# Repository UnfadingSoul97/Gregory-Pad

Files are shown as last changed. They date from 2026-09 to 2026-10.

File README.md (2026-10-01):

# Gregory-Pad
# 🚀 Custom 4x4 Mechanical Macro Pad

Welcome to my custom-engineered 4x4 macro pad project, designed as part of the **Hack Club Stardance/Hackpad** mission! This device features an ortholinear key matrix, advanced anti-ghosting rotary encoder input, and a high-resolution OLED status display screen.

---

## 🛠️ Hardware Specifications

- **Microcontroller:** Seeed Studio XIAO 
- **Key Layout:** 16-key (4x4 Matrix) uniform arrangement (custom `19.69 mm` spacing)
- **Key Switches:**  Gateron KS-3X1 Milky Yellow Pro Linear Switches with Kailh Hotswap Sockets
- **Accessory Cluster:** 
  - 1x Rotary Encoder Volume Dial (equipped with anti-ghosting input isolation diodes `D17` and `D18`)
  - 1x Waveshare 1.5-inch OLED Display Module (`26.86 mm` active square glass window)

---

## 📐 Enclosure Design & Architecture

The chassis is designed completely from scratch using **Onshape** using a highly rigid **Bottom-Up Sandwich Mount System**. My PCB is 110x110mm with curved edges

- **Layer Breakdown:**
  - **Top Bezel Cap:** 4.5mm thick protective frame with a flush 9mm encoder dial portal and a custom 27.5mm tolerance screen window. Totally clean top face with hidden screw anchors.
  - **Middle Spacer Walls:** 13mm thick hollow wall ring with integrated rounded internal corner fillets designed to smoothly scatter the underglow light from the RGB LED strip. Features an inline 15mm x 8.5mm side-mounted USB-C pass-through tunnel for maximum cable mold clearance.
  - **Bottom Base Plate:** 6mm thick solid floor slab featuring 4 deep mechanical counterbore screw pockets to hide the mounting hardware heads completely flush with the desk surface.
- **Tolerances:** Applied a micro-precise `0.4 mm` gap buffer across all internal pocket steps to easily absorb 3D printing plastic cooling shrinkage without component binding.

---

## 📂 Project Repository Structure

- `/KiCad/` - Contains the electrical schematic diagram sheets, netlists, trace footprints, and production Gerber fabrication zip bundles.
- `/CAD/` - Houses the 3D-printable `.STL` and `.STEP` mechanical mesh file models exported from Onshape.
- `README.md` - Documentation guide for my hardware build.

---

## 🎮 How to Assemble (My Build Process)

1. **The Circuit Module:** Solder the 1N4148 matrix diodes and hot-swap sockets onto the underside back face of the custom PCB. Solder the Seeed Studio XIAO module onto its dedicated landing pads.
2. **Switch Plate Assembly:** Click all 16 Gateron switches directly into the 1.5mm grey switch plate, then firmly press the completed PCB against the bottom pins until they securely seat into the friction-fit hotswap contacts.
3. **Chassis Fitment:** Drop the unified switch/PCB module down onto the internal wall shelf step of the lower middle case walls.
4. **Final Clamping:** Drop the long machine screws up through the bottom
   
## 🖼️ Image of Gregory
   

## 🖼️ Image of Schematic
   

## 🖼️ Image of PCB Design 
   

## 🖼️ How to fit
   Top Plate can be fitted on top of the switch plate 
   
   First PCB and switch plate are joined together and the switches places and then screwed on to the middle body from the top.(with an m2.2 screw)
   
   The Base,Middle body and top plate are screwed form the bottom with an m.3 screw and it is 19 mm deep.
   
   The switch plate fits inside the the top plate so it looks clean but u can view the top screws from the top.Its to 3d print the same size curves and place then into 
   a arm rest or accessory as per preference.
   

## BOM 👀
1x 1 SEEEDUINO XIAO RP2040

16x Gateron KS-3X1 Milky Yellow Pro (https://stackskb.com/store/gateron-ks-3x1p-pro-yellows/)

1x SSD1327 128x128 Oled display (5V VCC, 3.3V logic, I2C)(https://www.waveshare.com/1.5inch-oled-module.htm)

18x N4148 Switching Diodes

16x Kailh Hotswap Switch Sockets

4x 19mm long m3 screws

4x 3mm long m2.2 screws

1x Rotatory Encoder(Without Switch cuz no switch pins)

1x WS2812B RGB LED Strip (Addressable underglow) (https://harishprojects.com/products/ws2812b-rgb-strip-light-programmable-pixel-led-light-5-meter-length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)

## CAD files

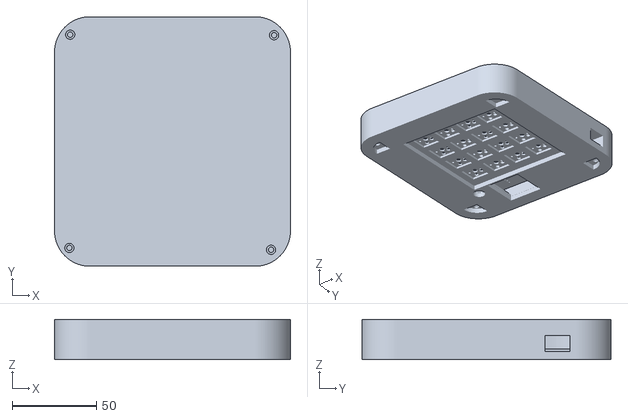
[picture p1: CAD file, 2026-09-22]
CAD/Gregory Assembled case.stl
140.0 x 148.0 x 24.0

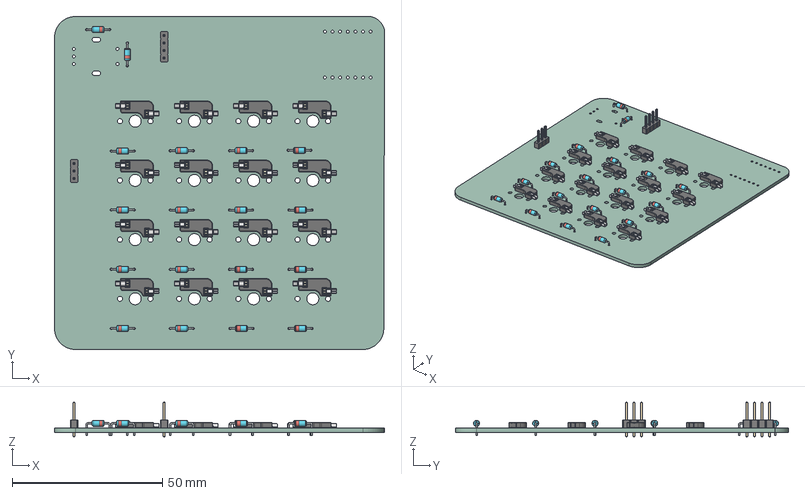
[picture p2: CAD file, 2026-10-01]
PCB/Gregory.step
109.8 x 110.8 x 11.5 mm
Kailh Socket v12 x 16
PinHeader_1x04_P254mm_Vertical
D_DO-35_SOD27_P7.62mm_Horizontal x 18
PinHeader_1x03_P254mm_Vertical
Gregory_PCB

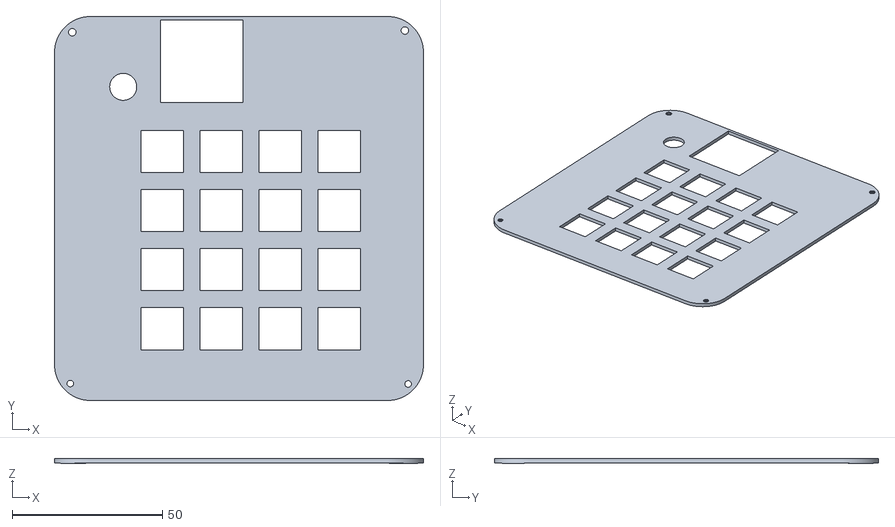
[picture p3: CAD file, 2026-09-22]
Production/Gregory Switch plate.stl
123.0 x 128.0 x 1.50

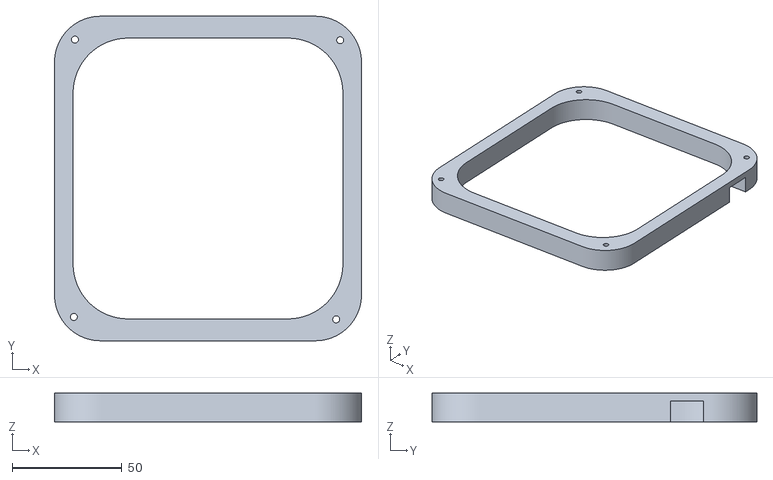
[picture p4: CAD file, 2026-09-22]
Production/Gregory Middle body.stl
140.0 x 148.0 x 13.0

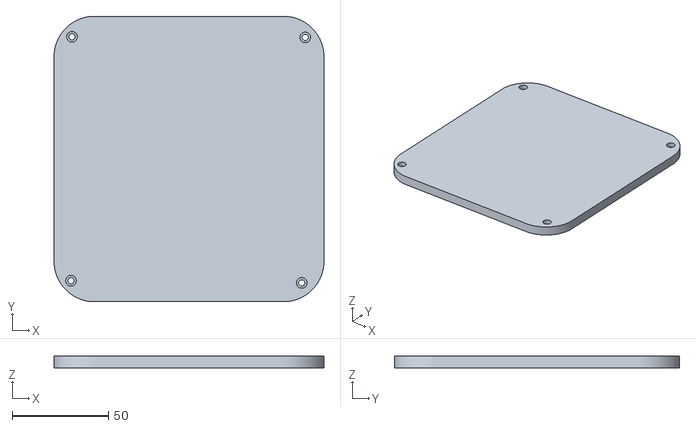
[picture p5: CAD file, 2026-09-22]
Production/Gregory base body.stl
140.0 x 148.0 x 6.00

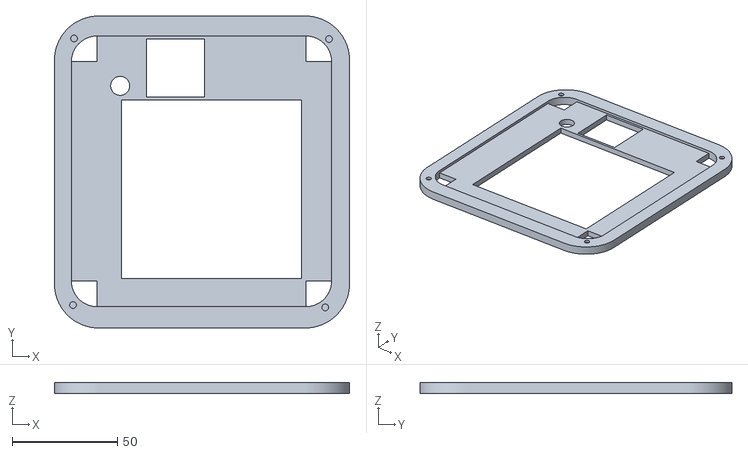
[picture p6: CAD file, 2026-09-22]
Production/Gregory Top plate bezzle.stl
140.0 x 148.0 x 5.00

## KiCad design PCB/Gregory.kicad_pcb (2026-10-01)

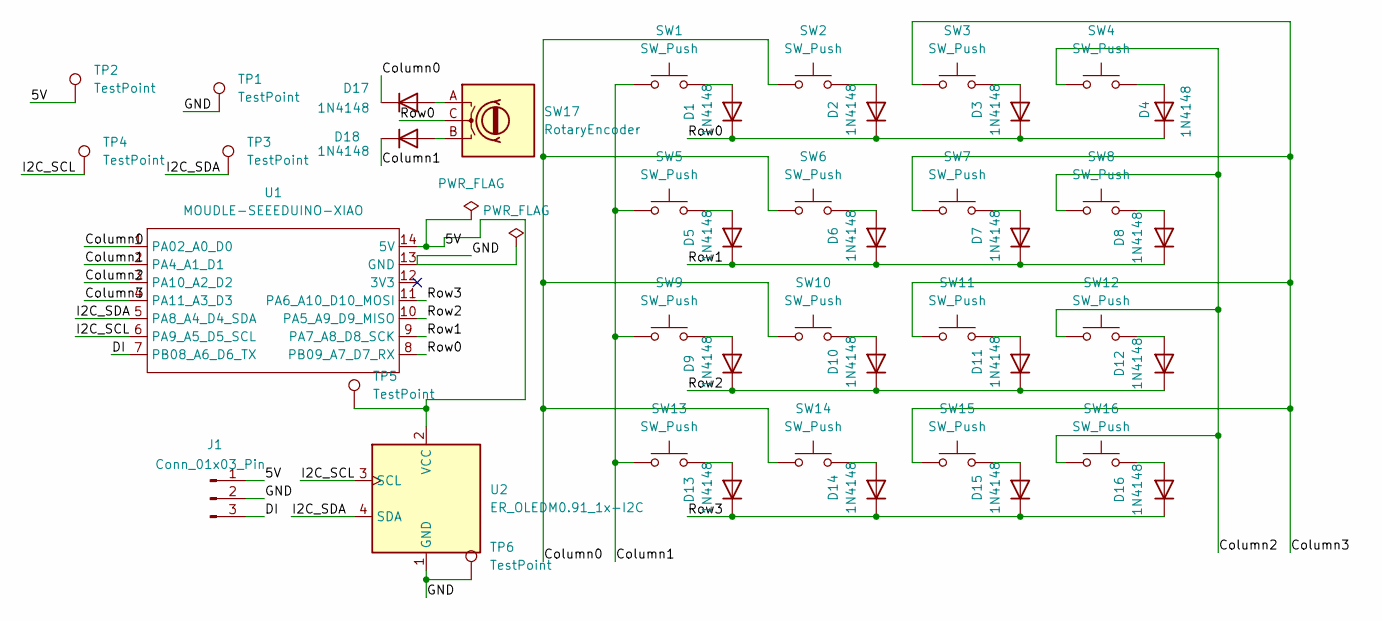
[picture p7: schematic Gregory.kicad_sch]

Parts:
D1, D2, D3, D4, D5, D6, D7, D8, D9, D10, D11, D12, D13, D14, D15, D16, D17, D18: 1N4148; D_DO-35_SOD27_P7.62mm_Horizontal
J1: Conn_01x03_Pin; PinHeader_1x03_P2.54mm_Vertical
SW1, SW2, SW3, SW4, SW5, SW6, SW7, SW8, SW9, SW10, SW11, SW12, SW13, SW14, SW15, SW16: SW_Push; MX-Hotswap-1U
SW17: RotaryEncoder; RotaryEncoder_Alps_EC11E_Vertical_H20mm
TP1, TP2, TP3, TP4, TP5, TP6: TestPoint; TestPoint_Pad_D1.5mm
U1: MOUDLE-SEEEDUINO-XIAO; XIAO-Generic-Hybrid-14P-2.54-21X17.8MM
U2: ER_OLEDM0.91_1x-I2C; PinHeader_1x04_P2.54mm_Vertical

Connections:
/5V: J1.1, TP2.1 (1_1), TP5.1 (1_1), U1.14 (5V), U2.2 (VCC)
/Column0: D17.1 (K), SW2.1, SW6.1, SW10.1, SW14.1, U1.1 (PA02_A0_D0)
/Column1: D18.1 (K), SW1.1, SW5.1, SW9.1, SW13.1, U1.2 (PA4_A1_D1)
/Column2: SW4.1, SW8.1, SW12.1, SW16.1, U1.3 (PA10_A2_D2)
/Column3: SW3.1, SW7.1, SW11.1, SW15.1, U1.4 (PA11_A3_D3)
/DI: J1.3, U1.7 (PB08_A6_D6_TX)
/GND: J1.2, TP1.1 (1_1), TP6.1 (1_1), U1.13 (GND), U2.1 (GND)
/I2C_SCL: TP4.1 (1_1), U1.6 (PA9_A5_D5_SCL), U2.3 (SCL)
/I2C_SDA: TP3.1 (1_1), U1.5 (PA8_A4_D4_SDA), U2.4 (SDA)
/Row0: D1.1 (K), D2.1 (K), D3.1 (K), D4.1 (K), SW17.C, U1.8 (PB09_A7_D7_RX)
/Row1: D5.1 (K), D6.1 (K), D7.1 (K), D8.1 (K), U1.9 (PA7_A8_D8_SCK)
/Row2: D9.1 (K), D10.1 (K), D11.1 (K), D12.1 (K), U1.10 (PA5_A9_D9_MISO)
/Row3: D13.1 (K), D14.1 (K), D15.1 (K), D16.1 (K), U1.11 (PA6_A10_D10_MOSI)
unnamed: D1.2 (A), SW1.2
unnamed: D2.2 (A), SW2.2
unnamed: D3.2 (A), SW3.2
unnamed: D4.2 (A), SW4.2
unnamed: D5.2 (A), SW5.2
unnamed: D6.2 (A), SW6.2
unnamed: D7.2 (A), SW7.2
unnamed: D8.2 (A), SW8.2
unnamed: D9.2 (A), SW9.2
unnamed: D10.2 (A), SW10.2
unnamed: D11.2 (A), SW11.2
unnamed: D12.2 (A), SW12.2
unnamed: D13.2 (A), SW13.2
unnamed: D14.2 (A), SW14.2
unnamed: D15.2 (A), SW15.2
unnamed: D16.2 (A), SW16.2
unnamed: D17.2 (A), SW17.A
unnamed: D18.2 (A), SW17.B

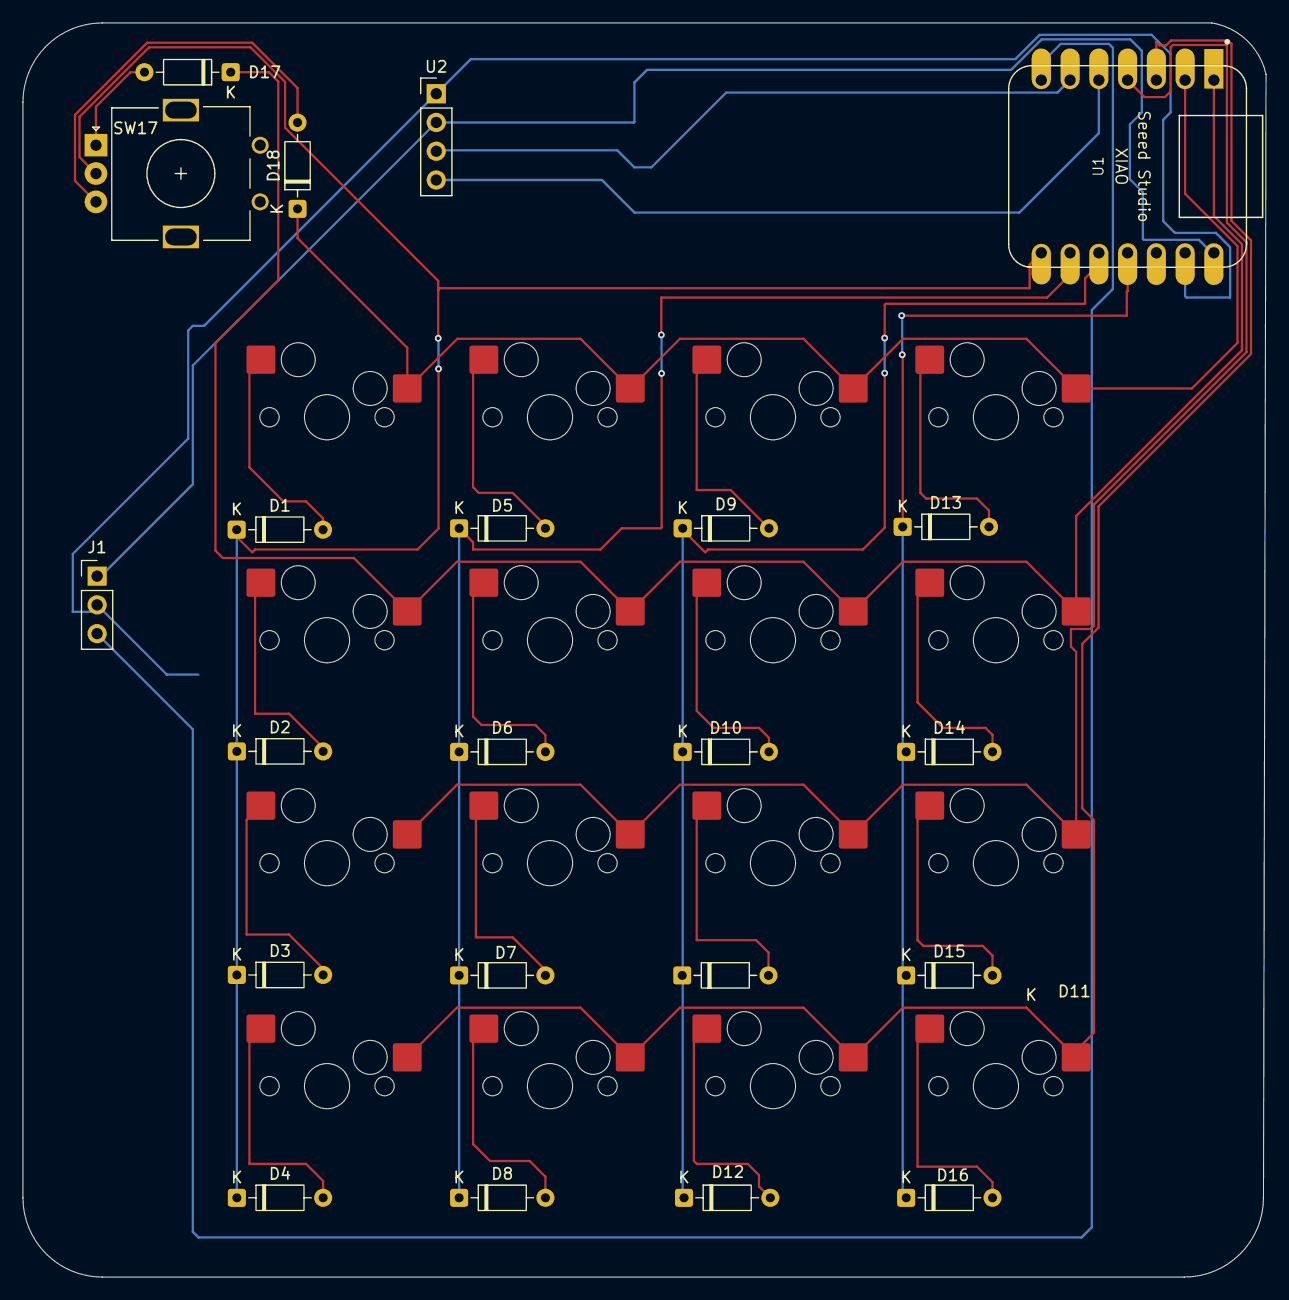
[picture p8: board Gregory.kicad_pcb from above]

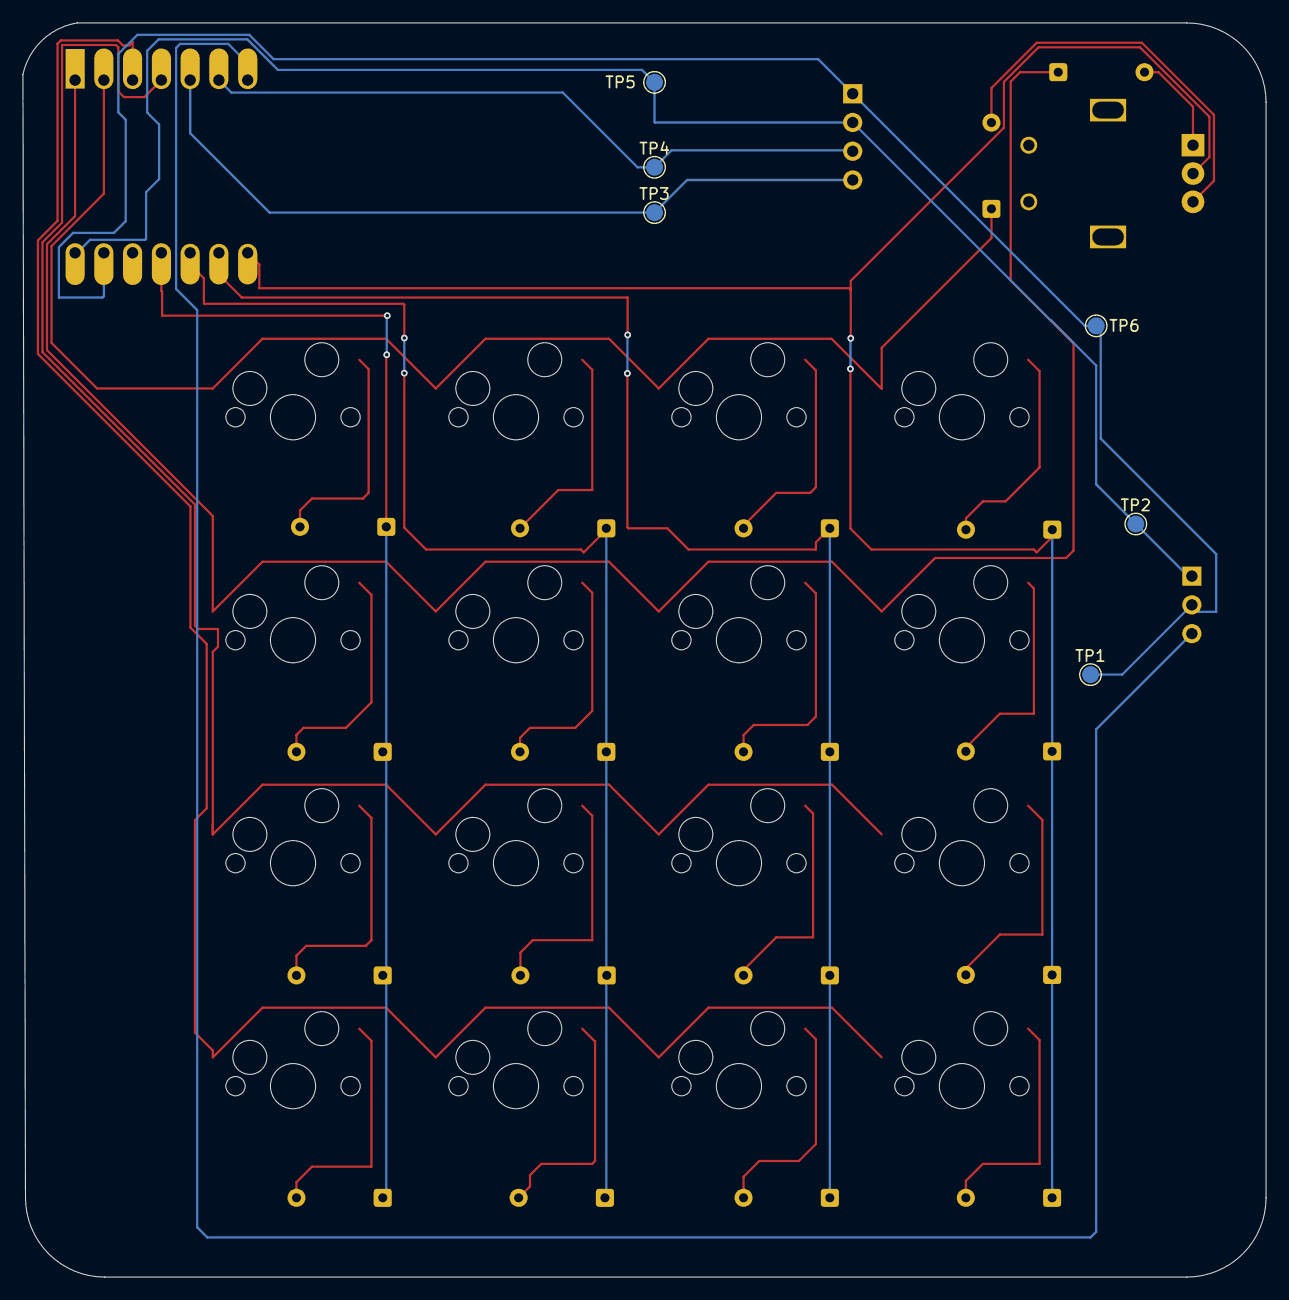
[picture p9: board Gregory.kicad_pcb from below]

Board: 2 copper layers, 109.8 x 110.8 mm, 44 parts (6 on the bottom side), 31 nets.

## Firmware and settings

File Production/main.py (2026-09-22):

import board
from kmk.kmk_keyboard import KMKKeyboard
from kmk.keys import KC
from kmk.scanners import DiodeOrientation
from kmk.modules.encoder import EncoderHandler
from kmk.extensions.rgb import RGB, AnimationModes

# Initialize the keyboard base engine
keyboard = KMKKeyboard()

# Configure your 4x4 matrix pin paths exactly to match your KiCad schematic
keyboard.col_pins = (board.D0, board.D1, board.D2, board.D3)
keyboard.row_pins = (board.D7, board.D8, board.D9, board.D10)

# Set your diode scanning direction (pointing from switches down to columns)
keyboard.diode_orientation = DiodeOrientation.COL2ROW

# Initialize the anti-ghosting volume wheel handler module
encoders = EncoderHandler()
keyboard.modules.append(encoders)

# Map your rotary encoder pin highways (Pin A, Pin B)
# Assumes DI goes to D6 and the other encoder pin goes to D5
encoders.pins = (
    (board.D6, board.D5, None, False), # (Pin A, Pin B, Click Pin, Is Inverted)
)

# Define your custom key bindings layout map (Layer 0)
keyboard.keymap = [
    [
        KC.N7, KC.N8, KC.N9, KC.MINUS,
        KC.N4, KC.N5, KC.N6, KC.PLUS,
        KC.N1, KC.N2, KC.N3, KC.SLASH,
        KC.N0, KC.DOT, KC.ENT, KC.SPC,
    ]
]

# Map your rotary encoder spinning actions to system media audio channels
encoders.map = [
    ( (KC.VOLU, KC.VOLD), ) # (Spin Clockwise = Vol Up, Spin Counter-Clockwise = Vol Down)
]

rgb = RGB(
    pixel_pin=board.D4,        # <-- Update this to the exact pin you wired to the RGB data line in KiCad!
    num_pixels=8,             # <-- Change this to the exact number of LEDs on your physical strip segment
    val_limit=150,            # Max brightness pad safety limiter (Saves battery/power load from the USB port)
    animation_mode=AnimationModes.RAINBOW, # Boots up with the classic gamer rainbow wave cycle effect
)
keyboard.extensions.append(rgb)

keyboard.extensions.append(rgb)

if __name__ == '__main__':
    keyboard.go()

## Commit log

2026-09-22 Correct switch type in assembly instructions
    Updated switch type from Leobog to Gateron in assembly instructions.
2026-09-22 Create PCB
2026-09-23 Finished the BOm and Addes steps to assemble the pad
    Added images and fitting instructions for assembly.
2026-10-01 Needed to fix the diodes they were inverted
2026-10-01 Had to fix the diodes placement cuz theyere inverted
2026-10-01 Replace PCB design image and add fitting details
    Updated PCB design image and added fitting instructions.
2026-11-04 didnt remove stl cuz though somone might need it
2026-11-04 Updated PCB file
2026-11-04 Standardize formatting in BOM.csv
    Formatted item entries for consistency in BOM.csv.
2026-11-04 Replace last row with N/A in BOM.csv
    Updated BOM.csv to replace the last row with N/A values.
2026-11-05 Update BOM.csv with revised cost estimates
2026-11-05 Correct cost for PCB in BOM.csv
    Updated the cost of an item in BOM.csv.
2026-11-05 Fix shipping cost format for Case item in BOM
    Updated the shipping cost format for the Case item.
2026-11-05 Update total cost in BOM.csv
    Updated total cost in BOM.csv from 66.19 to 72.62.
2026-11-06 Modify BOM.csv with new prices and totals
    Updated prices for Case and PCB, adjusted total.
2026-11-06 Update total cost in BOM.csv
    Updated total cost in BOM.csv from 72.57 to 72.72.
